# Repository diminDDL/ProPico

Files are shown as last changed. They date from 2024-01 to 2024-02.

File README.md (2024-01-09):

# ProPico
An RP2040 dev board improving on aspects of the pi pico.

### ⚠️ This project is still under development, reproduce at your own risk ⚠️
While I have assembled several of these boards and they seem to work, there is still some verification to be done, so don't expect this to be a fully finished project just yet.
## Features
- An LDO for power making the 3V3 supply much cleaner.
- Larger flash sizes up to 16MB (the higher capacities will likely require a different board revision due to the larger IC package) with binary indicators on the bottom so you remember which board has what.
- USB-C for power and programming, includes CC resistors meaning it'll work with modern USB-C chargers/cables.
- A reset button alongside the bootsel, allowing you to reboot into UF2 mode without having to unplug the board.
- Extra GPIO broken out and used:
    * GPIO 23 - connected to an extra LED.
    * GPIO 24 - connected to the EEPROM I2C line.
    * GPIO 25 - connected to the EEPROM I2C line and an LED (for compatibility with the pico led pinout).
    * GPIO 29 (ADC3) - replaces the 3V3_EN pin on the original pico, giving you an extra ADC pin.
- LM4040 voltage reference for the ADC.
- I2C EEPROM/FRAM onboard so you have easy to use non volatile storage.
- RUN pin exposed next to the debug port.

## Pinout
ProPico pinout

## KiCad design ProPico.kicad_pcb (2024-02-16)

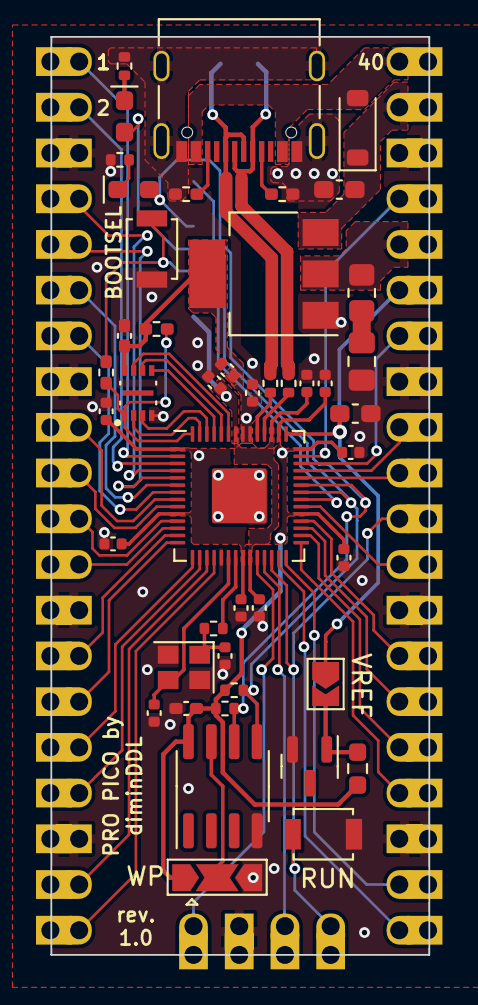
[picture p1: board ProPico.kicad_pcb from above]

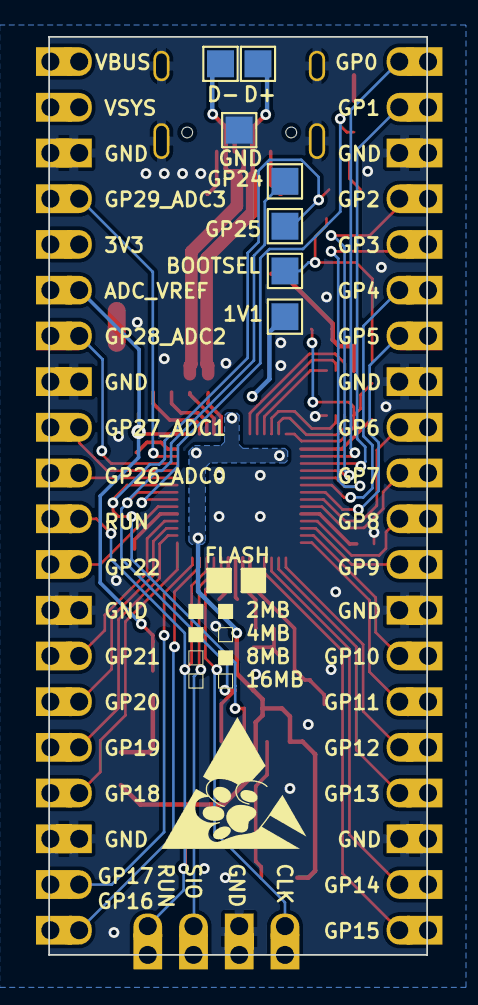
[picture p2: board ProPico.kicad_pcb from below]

Board: 2 copper layers, 21.0 x 51.0 mm, 55 parts (7 on the bottom side), 60 nets.

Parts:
C1, C5: 100n; C_0402_1005Metric_Pad0.74x0.62mm_HandSolder
C2, C3: 18p; C_0402_1005Metric
C4: 2.2u; C_0603_1608Metric_Pad1.08x0.95mm_HandSolder
C6: 10u; C_0805_2012Metric_Pad1.18x1.45mm_HandSolder
C7: 10n C0G; C_0603_1608Metric_Pad1.08x0.95mm_HandSolder
C8, C9, C11, C13, C14, C15, C16, C17, C18: 100n; C_0402_1005Metric
C10, C12: 1u; C_0402_1005Metric
D1: B5819W; D_SOD-123
D2, D3: LED; LED_0603_1608Metric_Pad1.05x0.95mm_HandSolder
J1: USB_C_Receptacle_USB2.0; USB_C_Receptacle_Palconn_UTC16-G
J2: SWD; Pico_4pin
J3: LEFT; Pico_20pin
J4: RIGHT; Pico_20pin
JP1: EEPROM_WP; SolderJumper-3_P2.0mm_Open_TrianglePad1.0x1.5mm
JP2: VREF; SolderJumper-2_P1.3mm_Open_TrianglePad1.0x1.5mm
R1: 1k; R_0402_1005Metric_Pad0.72x0.64mm_HandSolder
R2: DNP; R_0402_1005Metric_Pad0.72x0.64mm_HandSolder
R3, R4: 5.1k; R_0402_1005Metric_Pad0.72x0.64mm_HandSolder
R5, R10, R11, R12, R13: 1k; R_0402_1005Metric
R6: 470mOhm; R_0805_2012Metric_Pad1.20x1.40mm_HandSolder
R7: 150; R_0603_1608Metric_Pad0.98x0.95mm_HandSolder
R8, R9: 27; R_0402_1005Metric
SW1: BOOTSEL; SW_SPST_B3U-1000P
SW2: RES; SW_SPST_B3U-1000P
TP1: BOOTSEL; TestPoint_Pad_1.5x1.5mm
TP2: VREG; TestPoint_Pad_1.5x1.5mm
TP3: GP25; TestPoint_Pad_1.5x1.5mm
TP4: GND; TestPoint_Pad_1.5x1.5mm
TP5: D+; TestPoint_Pad_1.5x1.5mm
TP6: GP24; TestPoint_Pad_1.5x1.5mm
TP7: D-; TestPoint_Pad_1.5x1.5mm
U1: FM24CL16B; SOIC-8_3.9x4.9mm_P1.27mm
U2: W25Q16JVUXIQ; IC_W25Q16JVUXIQ_TR
U3: AMS1117-3.3; SOT-223-3_TabPin2
U4: LM4040DBZ-3; SOT-23
U5: RP2040; RP2040-QFN-56
Y1: ECS-120-12-36-AGN-TR3; Crystal_SMD_2520-4Pin_2.5x2.0mm

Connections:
+1V1: C8.1, C9.1, C10.1, TP2.1, U5.23 (DVDD), U5.45 (VREG_VOUT), U5.50 (DVDD)
+3V3: C1.1, C5.1, C11.1, C12.1, C13.1, C14.1, C15.1, C16.1, C17.1, C18.1, J4.16, JP1.1 (A), R2.1, R6.2, R7.2, R10.1, R11.1, U1.8 (VDD), U2.8 (VCC), U3.2 (VO), U5.1 (IOVDD), U5.10 (IOVDD), U5.22 (IOVDD), U5.33 (IOVDD), U5.42 (IOVDD), U5.44 (VREG_IN), U5.48 (USB_VDD), U5.49 (IOVDD)
+5V: C4.1, D1.1 (K), J4.19, U3.3 (VI)
/3V0_VREF: JP2.2 (B), R7.1, U4.1 (K)
/ADC_VREF: C7.1, J4.15, JP2.1 (A), U5.43 (ADC_AVDD)
/D+: J1.A6 (D+), J1.B6 (D+), R8.1, TP5.1
/D-: J1.A7 (D-), J1.B7 (D-), R9.1, TP7.1
/DN: R9.2, U5.46 (USB_DM)
/DP: R8.2, U5.47 (USB_DP)
/EEPROM_SCL: D3.2 (A), R11.2, TP3.1, U1.6 (SCL), U5.37 (GPIO25)
/EEPROM_SDA: R10.2, TP6.1, U1.5 (SDA), U5.36 (GPIO24)
/EEPROM_WP: JP1.2 (C), U1.7 (WP)
/GPIO0: J3.1, U5.2 (GPIO0)
/GPIO1: J3.2, U5.3 (GPIO1)
/GPIO2: J3.4, U5.4 (GPIO2)
/GPIO3: J3.5, U5.5 (GPIO3)
/GPIO4: J3.6, U5.6 (GPIO4)
/GPIO5: J3.7, U5.7 (GPIO5)
/GPIO6: J3.9, U5.8 (GPIO6)
/GPIO7: J3.10, U5.9 (GPIO7)
/GPIO8: J3.11, U5.11 (GPIO8)
/GPIO9: J3.12, U5.12 (GPIO9)
/GPIO10: J3.14, U5.13 (GPIO10)
/GPIO11: J3.15, U5.14 (GPIO11)
/GPIO12: J3.16, U5.15 (GPIO12)
/GPIO13: J3.17, U5.16 (GPIO13)
/GPIO14: J3.19, U5.17 (GPIO14)
/GPIO15: J3.20, U5.18 (GPIO15)
/GPIO16: J4.1, U5.27 (GPIO16)
/GPIO17: J4.2, U5.28 (GPIO17)
/GPIO18: J4.4, U5.29 (GPIO18)
/GPIO19: J4.5, U5.30 (GPIO19)
/GPIO20: J4.6, U5.31 (GPIO20)
/GPIO21: J4.7, U5.32 (GPIO21)
/GPIO22: J4.9, U5.34 (GPIO22)
/GPIO23: D2.2 (A), U5.35 (GPIO23)
/GPIO26_ADC0: J4.11, U5.38 (GPIO26_ADC0)
/GPIO27_ADC1: J4.12, U5.39 (GPIO27_ADC1)
/GPIO28_ADC2: J4.14, U5.40 (GPIO28_ADC2)
/GPIO29_ADC3: J4.17, U5.41 (GPIO29_ADC3)
/QSPI_SCLK: U2.6 (CLK), U5.52 (QSPI_SCLK)
/QSPI_SD0: U2.5 (DI(IO0)), U5.53 (QSPI_SD0)
/QSPI_SD1: U2.2 (DO(IO1)), U5.55 (QSPI_SD1)
/QSPI_SD2: U2.3 (IO2), U5.54 (QSPI_SD2)
/QSPI_SD3: U2.7 (IO3), U5.51 (QSPI_SD3)
/QSPI_SS: R1.1, R2.2, U2.1 (~CS), U5.56 (QSPI_SS)
/RUN: J2.4, J4.10, SW2.1, U5.26 (RUN)
/SWCLK: J2.1, U5.24 (SWCLK)
/SWD: J2.3, U5.25 (SWD)
/XIN: C2.1, U5.20 (XIN), Y1.3
/XOUT: R5.1, U5.21 (XOUT)
GND: C1.2, C2.2, C3.2, C4.2, C5.2, C6.2, C7.2, C8.2, C9.2, C10.2, C11.2, C12.2, C13.2, C14.2, C15.2, C16.2, C17.2, C18.2, J1.A1 (GND), J1.A12 (GND), J1.B1 (GND), J1.B12 (GND), J1.S1 (SHIELD), J2.2, J3.3, J3.8, J3.13, J3.18, J4.3, J4.8, J4.13, J4.18, JP1.3 (B), R3.2, R4.2, R12.2, R13.2, SW1.1, SW2.2, TP4.1, U1.4 (VSS), U2.4 (GND), U3.1 (GND), U4.2 (A), U5.19 (TESTEN), U5.57 (GND), Y1.2, Y1.4
unnamed: C3.1, R5.2, Y1.1
unnamed: C6.1, R6.1
unnamed: D2.1 (K), R12.1
unnamed: D3.1 (K), R13.1
unnamed: J1.A5 (CC1), R4.1
unnamed: J1.B5 (CC2), R3.1
unnamed: R1.2, SW1.2, TP1.1
VBUS: D1.2 (A), J1.A4 (VBUS), J1.A9 (VBUS), J1.B4 (VBUS), J1.B9 (VBUS), J4.20

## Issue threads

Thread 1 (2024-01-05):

ESD Protection

smeisner, 2024-01-05:
Nice work so far!!

Looking at the design, I was curious about static discharge protection. Is that what R8 & R9 are for? I don't have the latest version of Kicad, so I couldn't open the schematics, but looking at the BOM, it looks like these resistors may be for ESD.

diminDDL, 2024-01-05:
From, [Hardware design with RP2040](https://datasheets.raspberrypi.com/rp2040/hardware-design-with-rp2040.pdf):

>  these I/Os do require 27Ω series termination resistors (R3 and R4 in Figure 9), placed close to the chip, in order to meet the USB impedance specification.

Regarding ESD, the RP2040 meets all the standard ESD specifications of 1-2kV Human Body Model, additional USB ESD protection may be added later depending on the available board space and cost.

smeisner, 2024-01-06:
Thanks for the rely! I am working on a ESP32-based thermostat  (https://github.com/smeisner/smart-thermostat) and was concerned about ESD. This is why I was asking. I am doing a final rev of the PCB and was hoping to incorporate protection into it.

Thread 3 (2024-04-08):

Add support for precision XTAL/TCXO

mungewell, 2024-04-08:
For my own project, I needed a more accurate XTAL... obviously not everyone needs this, or wants to spend the extra money. However there is a nice 'hack'.

By adding 2 resistor footprints to connect to pin 2 of the XTAL, 'we' could configure the board to take either a passive XTAL or a (user performed modification) TCXO. Only extra one resistor, connecting to ground, would be fitted for mass production.

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

Would you consider adding this?

More info on what I am doing.
https://github.com/mungewell/pico-timecode/issues/4

diminDDL, 2024-04-10:
While it looks interesting, there is some hustle associated with re-routing the board for this admittedly niche use case, I will leave the issue open and in case there will be more support/requests I'll consider it.

diminDDL, 2024-04-19:
Upon further thought I think I might add it at some point in a similar way as described where it can be optionally populated as needed.

mungewell, 2024-04-20:
Cool, thanks. I'm sure that there are others out there would also benefit.

I'm working on some automated testing, using `uhubctl` to cycle boards on/off and perform calibration process with my. This should help document variance between stock XTAL and TCXO...

mungewell, 2024-10-18:
After being busy with other stuff this summer, I have restarted work on my Pico-Timecode project and have some test data showing how the stock XTAL is behaving.
https://github.com/mungewell/pico-timecode/issues/4#issuecomment-2420900643

I appreciate not everyone needs this level of precision... My particular needs are sub-1PPM accuracy over varying temp, so a TCXO is probably a must.

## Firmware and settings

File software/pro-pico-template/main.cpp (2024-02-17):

#include <stdio.h>
#include "pico/stdlib.h"
#include "pico/stdio.h"
#include "hardware/pio.h"
#include "hardware/clocks.h"
#include "hardware/vreg.h"
#include "blink.pio.h"
#include "Memory.hpp"

// ProPico pinout definitions
#define LED0 25
#define LED1 23

// Redefine the default LED to one that won't interfere with the I2C EEPROM
#define PICO_DEFAULT_LED_PIN 23

// I2C EEPROM pinout definitions
#define EEPROM_SDA 24
#define EEPROM_SCL 25


int main() {
    // Overclocking if needed
    // 400Mhz should be stable for most RP2040 chips, adjust the voltage as needed
    // Also don't forget to enable the XIP divider in CMakeLists.txt
    // vreg_set_voltage(VREG_VOLTAGE_MAX);
    // set_sys_clock_khz(400000, true);

    stdio_init_all();

    // setup PIO to blink the LED
    static const float pio_freq = 1000;
    PIO pio = pio0;
    uint sm = pio_claim_unused_sm(pio, true);
    uint offset = pio_add_program(pio, &blink_program);
    float div = (float)clock_get_hz(clk_sys) / pio_freq;
    blink_program_init(pio, sm, offset, LED1, div);
    pio_sm_set_enabled(pio, sm, true);

    // Initialize the I2C EEPROM
    gpio_set_function(EEPROM_SDA, GPIO_FUNC_I2C);
    gpio_set_function(EEPROM_SCL, GPIO_FUNC_I2C);
    i2c_init(i2c0, DEFAULT_EEPROM_CLOCK);

    // Initialize the Memory class
    Memory memory(0x50, i2c0);

    sleep_ms(1000);
    // Check if the EEPROM is connected
    if (memory.verifyConnection()) {
        printf("EEPROM connected\n");
    } else {
        printf("EEPROM not connected\n");
        return 0;
    }

    if(memory.readWord(0) != 0xDEADBEEF)
    {
        printf("EEPROM not initialized\n");
        // Perform a self test on the EEPROM
        int errors = memory.selfTest();
        printf("Self test found %d errors\n", errors);

        // Write some of our own data to the EEPROM
        memory.writeWord(0, 0xDEADBEEF);
        memory.writeWord(4, 0xCAFEBABE);
        memory.writeWord(8, 0x12345678);
    }else{
        printf("EEPROM initialized, we will just read from it\n");
    }

    while (true) {
        // Read the data back
        printf("Read back: 0x%08X\n", memory.readWord(0));
        printf("Read back: 0x%08X\n", memory.readWord(4));
        printf("Read back: 0x%08X\n", memory.readWord(8));
        sleep_ms(1000);
    }
}

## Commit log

2022-12-28 starting the schematic
    [ProPico.kicad_pcb, ProPico.kicad_sch]
2023-10-29 started layout
    [ProPico.kicad_pcb, ProPico.kicad_sch]
2023-11-01 progress on layout
    [ProPico.kicad_pcb, ProPico.kicad_sch]
2023-11-03 finished layout
    [ProPico.kicad_pcb]
2023-11-03 finished erc
    [ProPico.kicad_pcb]
2023-11-04 finished silkscreen
    [ProPico.kicad_pcb, ProPico.kicad_sch]
2023-11-04 added render, fixed spelling mistake
    [ProPico.kicad_pcb]
2023-11-24 added BOM
2023-12-22 updated schematic
    [ProPico.kicad_sch]
2023-12-22 made schematic less cringe
    [ProPico.kicad_pcb]
2024-02-10 wip adding part numbers to components
    [ProPico.kicad_sch]
2024-02-10 added part numbers to everything in the schematic
    [ProPico.kicad_sch]
2024-02-16 changed the names of some nets to be more logical
    [ProPico.kicad_pcb, ProPico.kicad_sch]
